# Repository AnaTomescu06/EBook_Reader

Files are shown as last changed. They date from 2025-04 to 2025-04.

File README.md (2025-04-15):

# OpenBook – Proiect TSC 2025

## Descriere generală

**OpenBook** este un dispozitiv portabil de tip e-book reader, conceput ca soluție open-source, eficientă energetic și scalabilă. Acesta se bazează pe microcontrolerul **ESP32-C6-WROOM**, având ca funcții principale afișarea de conținut pe un ecran e-paper și monitorizarea parametrilor de mediu (temperatură, umiditate, CO2, particule).

Dispozitivul permite salvarea datelor colectate pe un card microSD și oferă control prin intermediul unor butoane fizice.

## Diagramă bloc
Pollution Tracker

## Funcționalitate hardware

Dispozitivul este structurat în jurul modulului **ESP32-C3-WROOM**, care gestionează toate interfețele de comunicare cu componentele externe.

### ESP32-C3-WROOM
- Microcontroler principal cu suport pentru **Wi-Fi** și **BLE**
- Interfețe: **SPI**, **I2C**, **UART**
- Alimentare: **3.3V** prin LDO

### Sistem de alimentare
- **USB-C** pentru alimentare externă și comunicare
- **MCP73832** pentru managementul încărcării bateriei Li-Po
- **LDO 3.3V** pentru alimentarea logicii
- **DC-DC 5V** pentru alimentarea senzorilor PM și CO2

### Senzori
- **BME680** (I2C, 3.3V) - temperatură, umiditate, gaze
- **MH-Z19B** (UART, 5V) - CO2
- **PMSA003** (UART, 5V) - particule fine (PM2.5)

### Ecran
- **E-paper monocrom 1.5''** cu rezoluție 200x200 px
- Interfață SPI comună cu cardul SD

### Card SD
- Slot microSD pentru stocarea de date/text
- Interfață SPI

### Butoane
- 3 butoane tactile conectate la pinii GPIO pentru interacțiune cu utilizatorul

## Bill of Materials (BOM)

| Part | Device | Datasheet |
|---|---|---|
| CHG_LED | ADAFRUIT_LEDCHIP-LED0603 | [ADAFRUIT_LEDCHIP-LED0603](https://www.snapeda.com/parts/KP-1608SURCK/Kingbright/view-part/?ref=search&t=LED%200603) |
| SJ1 | SJ | [SJ](https://grabcad.com/library/solder-jumpers-1) |
| EPD_C5 | EAGLE-LTSPICE_CC0402 | [EAGLE-LTSPICE_CC0402](https://www.snapeda.com/parts/PGB1010603MR/Littelfuse/view-part/?ref=eda) |
| R3 | ESP32_WROVER_EAGLE-LTSPICE_RR0402 | (https://componentsearchengine.com/part-view/R0402%201%25%20100%20K%20(RC0402FR-07100KL)/YAGEO) |
| R1_PWRUSB | ESP32_WROVER_EAGLE-LTSPICE_RR0402 | (https://componentsearchengine.com/part-view/R0402%201%25%20100%20K%20(RC0402FR-07100KL) |
| C4_USB | EAGLE-LTSPICE_CC0402 | [EAGLE-LTSPICE_CC0402](https://componentsearchengine.com/part-view/CC0402MRX5R5BB106/YAGEO) |
| C1, C2, C6, C8, C9, C10, C_DELAY | ESP32_WROVER_EAGLE-LTSPICE_CC0402 | [ESP32_WROVER_EAGLE-LTSPICE_CC0402](https://componentsearchengine.com/part-view/CC0402MRX5R5BB106/YAGEO) |
| C3 | RCL_CPOL-EUCT3528 | [RCL_CPOL-EUCT3528](https://componentsearchengine.com/part-view/CC0402MRX5R5BB106/YAGEO) |
| R1, R1_PINH, R1_PINH1, R2_PINH, R2_PINH1, R4, R5, R6, R7, R8, R9, R10, R_BOOT, R_CHANGE, R_CL1, R_RESET | ESP32_WROVER_EAGLE-LTSPICE_RR0402 | [ESP32_WROVER_EAGLE-LTSPICE_RR0402](https://componentsearchengine.com/part-view/R0402%201%25%20100%20K%20(RC0402FR-07100KL)/YAGEO) |
| C7 | ESP32_WROVER_EAGLE-LTSPICE_CC0402 | [ESP32_WROVER_EAGLE-LTSPICE_CC0402](https://componentsearchengine.com/part-view/CC0402MRX5R5BB106/YAGEO) |
| J4 | 112A-TAAR-R03_ATTEND | [112A-TAAR-R03_ATTEND](https://store.comet.srl.ro/Catalogue/Product/43497/) |
| R_CAPACITOR | ESP32_WROVER_EAGLE-LTSPICE_RR0402 | [ESP32_WROVER_EAGLE-LTSPICE_RR0402](https://componentsearchengine.com/part-view/R0402%201%25%20100%20K%20(RC0402FR-07100KL)/YAGEO) |
| C5 | ESP32_WROVER_EAGLE-LTSPICE_CC0402 | [ESP32_WROVER_EAGLE-LTSPICE_CC0402](https://componentsearchengine.com/part-view/CC0402MRX5R5BB106/YAGEO) |
| EPD_C6, EPD_C7, EPD_C8, EPD_C9, EPD_C10, EPD_C11, EPD_C12 | EAGLE-LTSPICE_CC0402 | [EAGLE-LTSPICE_CC0402](https://componentsearchengine.com/part-view/CC0402MRX5R5BB106/YAGEO) |
| EPD_C1, EPD_C2 | ESP32_WROVER_EAGLE-LTSPICE_CC0402 | [ESP32_WROVER_EAGLE-LTSPICE_CC0402](https://componentsearchengine.com/part-view/CC0402MRX5R5BB106/YAGEO) |
| R2 | ESP32_WROVER_EAGLE-LTSPICE_RR0402 | [ESP32_WROVER_EAGLE-LTSPICE_RR0402](https://componentsearchengine.com/part-view/R0402%201%25%20100%20K%20(RC0402FR-07100KL)/YAGEO) |
| R1_BAT | ESP32_WROVER_EAGLE-LTSPICE_RR0402 | [ESP32_WROVER_EAGLE-LTSPICE_RR0402](https://componentsearchengine.com/part-view/R0402%201%25%20100%20K%20(RC0402FR-07100KL)/YAGEO) |
| Q1, Q2 | ESP32_WROVER_SPARKFUN-DISCRETESEMI_MOSFET_PCH-DMG2305UX-7 | [ESP32_WROVER_SPARKFUN-DISCRETESEMI_MOSFET_PCH-DMG2305UX-7](https://componentsearchengine.com/part-view/DMG2305UX-7/Diodes%20Incorporated) |
| R2_BAT | ESP32_WROVER_EAGLE-LTSPICE_RR0402 | [ESP32_WROVER_EAGLE-LTSPICE_RR0402](https://componentsearchengine.com/part-view/R0402%201%25%20100%20K%20(RC0402FR-07100KL)/YAGEO) |
| C5_USB | EAGLE-LTSPICE_CC0402 | [EAGLE-LTSPICE_CC0402](https://componentsearchengine.com/part-view/CC0402MRX5R5BB106/YAGEO) |
| C1_BAT, C1_BAT1, C1_BAT2, C2_BAT | ESP32_WROVER_EAGLE-LTSPICE_CC0402 | [ESP32_WROVER_EAGLE-LTSPICE_CC0402](https://componentsearchengine.com/part-view/CC0402MRX5R5BB106/YAGEO) |
| C4 | ESP32_WROVER_EAGLE-LTSPICE_CC0402 | [ESP32_WROVER_EAGLE-LTSPICE_CC0402](https://componentsearchengine.com/part-view/CC0402MRX5R5BB106/YAGEO) |
| R2-USB, R2-USB1 | ESP32_WROVER_EAGLE-LTSPICE_RR0402 | [ESP32_WROVER_EAGLE-LTSPICE_RR0402](https://componentsearchengine.com/part-view/R0402%201%25%20100%20K%20(RC0402FR-07100KL)/YAGEO) |
| L1 | 744043680IND_4828-WE-TPC_WRE | [744043680IND_4828-WE-TPC_WRE](https://eu.mouser.com/ProductDetail/Wurth-Elektronik/744043680?qs=PGXP4M47uW6VkZq%252BkzjrHA%3D%3D) |
| IC1 | BD5229G-TR | [BD5229G-TR](https://componentsearchengine.com/part-view/BD5229G-TR/ROHM%20Semiconductor) |
| SENSOR2 | ESP32_WROVER_BME680_BME680 | [ESP32_WROVER_BME680_BME680](https://www.snapeda.com/parts/BME680/Bosch/view-part/?welcome=home) |
| BUTTON_CUSYOMV1 |BUTTON_CUSYOMV1 | [BUTTON_CUSYOMV1](https://industry.panasonic.com/global/en/products/control/switch/light-touch/number/evqpuj02k) |
| C10_SUPERCAP | CPH3225A | [CPH3225A](https://www.snapeda.com/parts/CPH3225A/Seiko+Instruments/view-part/?ref=snap) |
| U3 | DS3231SN# | [DS3231SN#](https://www.snapeda.com/parts/DS3231SN%23/Analog+Devices/view-part/?ref=snap) |
| U2 | ESP32-C6-WROOM-1-N8 | [ESP32-C6-WROOM-1-N8](https://www.snapeda.com/parts/ESP32-C6-WROOM-1-N8/Espressif+Systems/view-part/?ref=eda) |
| PFMF.050.1 | ESP32C6_VARISTORCN1812 | [ESP32C6_VARISTORCN1812](https://www.mouser.co.uk/ProductDetail/EPCOS-TDK/B72520T0350K062?qs=dEfas%2FXlABIszF52uu7vrg%3D%3D) |
| D2, D7 | ESP32_WROVER_AVX---SD0805S020S1R0_AVX_SD0805S020S1R0_0_0AVX_SD0805S020S1R0_0_0 | [ESP32_WROVER_AVX---SD0805S020S1R0_AVX_SD0805S020S1R0_0_0AVX_SD0805S020S1R0_0_0](https://eu.mouser.com/ProductDetail/KYOCERA-AVX/SD0805S020S1R0?qs=jCA%252BPfw4LHbpkAoSnwrdjw%3D%3D) |
| U5 | ESP32_WROVER_SPARKFUN-IC-POWER_MCP73831 | [ESP32-C6-WROOM-1-N8](https://componentsearchengine.com/part-view/MCP73831T-2ATI%2FOT/Microchip) |
| J1 | FH34SRJ-24S-0.5SH_99_ | [FH34SRJ-24S-0.5SH_99_](https://componentsearchengine.com/part-view/XC6220A331MR-G/Torex) |
| U4 | MAX17048G+T10 | [MAX17048G+T10](https://www.snapeda.com/parts/MAX17048G+T10/Analog+Devices/view-part/?ref=snap) |
| D3, D4, D5 | MBR0530 | [MBR0530](https://www.snapeda.com/parts/MBR0530/Onsemi/view-part/?ref=snap) |
| D6, D8, D9, D10, D11, D12 | PGB1010603MR | [PGB1010603MR](https://www.snapeda.com/parts/PGB1010603MR/Littelfuse/view-part/?ref=snap) |
| J3 | QWIIC_CONNECTORJS-1MM | [QWIIC_CONNECTORJS-1MM](https://www.snapeda.com/parts/PRT-14417/SparkFun%20Electronics/view-part/?ref=search&t=qwiic) |
| J2 | SAMACSYS_PARTS_USB4110-GF-A | (https://componentsearchengine.com/part-view/USB4110-GF-A/GCT%20(GLOBAL%20CONNECTOR%20TECHNOLOGY) |
| Q3 | SI1308EDL-T1-GE3 | [SI1308EDL-T1-GE3](https://componentsearchengine.com/part-view/SI1308EDL-T1-GE3/Vishay) |
| TP1, TP2, TP3, TP4, TP5, TP6, TP7, TP8, TP9, TP10, TP11, TP12, TP13, TP14, TP15, TP16, TP17 | TPTP20R | [facute de mine] |
| D1 | USBLC6-2SC6Y | [USBLC6-2SC6Y](https://www.snapeda.com/parts/USBLC6-2SC6Y/STMicroelectronics/view-part/?ref=snap) |
| U1 | W25Q512JVEIQ | [W25Q512JVEIQ](https://www.snapeda.com/parts/W25Q512JVEIQ/Winbond+Electronics/view-part/?ref=snap) |
| IC4 | XC6220A331MR-G | [XC6220A331MR-G](https://componentsearchengine.com/part-view/XC6220A331MR-G/Torex) |

## Alocare pini ESP32-C3

| Pin ESP32-C3 | Componentă  | Funcție / Motiv |
|---|---|---|
| GPIO1 | BME680 | I2C - SDA |
| GPIO2 | BME680 | I2C - SCL |
| GPIO3 | PMSA003 | UART RX pentru senzor PM |
| GPIO4 | SD Card | SPI Chip Select (CS) |
| GPIO5 | E-Ink | Data/Command |
| GPIO6 | E-Ink & SD  | SPI Clock (SCK) |
| GPIO7 | E-Ink & SD  | SPI MOSI (date) |
| GPIO8 | Buton 1 | Control meniu / pagină |
| GPIO9 | Buton 2 | Control meniu / pagină |
| GPIO10 | E-Ink | SPI Chip Select (CS) |
| GPIO11 | Flash ext.  | CS rezervat, neutilizat momentan |
| GPIO12 | USB | USB D- |
| GPIO13 | USB | USB D+ |
| GPIO18 | MH-Z19B | UART TX pentru senzor CO2 |
| GPIO19 | Buton 3 | Confirmare / acțiune suplimentară  |

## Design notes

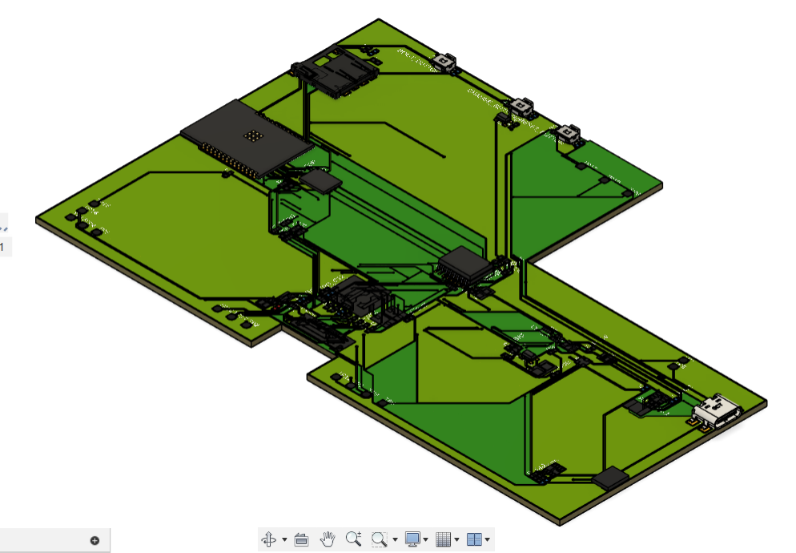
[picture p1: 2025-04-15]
Images/Screenshot 2025-04-15 091844.png

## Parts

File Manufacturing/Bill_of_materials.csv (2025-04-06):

BOOT_BUTTON | 36.07 | 115.33 | 180.00 | BUTTON_CUSYOMV1 | MYBUTTON
C1 | 18.81 | 107.10 | 90.00 |  | EAGLE-LTSPICE_C0402
C10 | 64.88 | 114.96 | 90.00 | 100nF | EAGLE-LTSPICE_C0402
C11 | 33.05 | 115.06 | 90.00 | 100nF | EAGLE-LTSPICE_C0402
C1_BAT | 92.31 | 28.88 | 90.00 | 4.7uF | ESP32_WROVER_EAGLE-LTSPICE_C0402
C1_BAT1 | 78.65 | 26.12 | 90.00 | 4.7uF | EAGLE-LTSPICE_C0402
C1_BAT2 | 167.29 | 58.42 | 90.00 | 4.7uF | EAGLE-LTSPICE_C0402
C2 | 20.80 | 107.17 | 90.00 |  | EAGLE-LTSPICE_C0402
C2_BAT | 88.52 | 28.88 | 90.00 | 4.7uF | EAGLE-LTSPICE_C0402
C3 | 137.11 | 45.80 | 90.00 | 100uF TANT | RCL_CT3528
C4 | 80.06 | 26.14 | 90.00 | 4.7uF/25V | ESP32_WROVER_EAGLE-LTSPICE_C0402
C4_USB | 90.42 | 28.90 | 90.00 | 100nF | ESP32_WROVER_EAGLE-LTSPICE_C0402
C5 | 169.02 | 14.68 | 90.00 | 1uF | EAGLE-LTSPICE_C0402
C5_USB | 94.23 | 28.90 | 90.00 | 4.7uF | ESP32_WROVER_EAGLE-LTSPICE_C0402
C6 | 80.02 | 114.96 | 90.00 | 100nF | EAGLE-LTSPICE_C0402
C7 | 159.19 | 57.10 | 90.00 |  | EAGLE-LTSPICE_C0402
C8 | 106.29 | 57.44 | 269.60 | CPH3225A | CAPCP3225X100N
C9 | 39.90 | 114.96 | 90.00 | 100nF | EAGLE-LTSPICE_C0402
CHANGE_BUTTON | 61.06 | 115.43 | 180.00 | BUTTON_CUSYOMV1 | MYBUTTON
CHG_LED | 130.94 | 57.55 | 90.00 |  | ADAFRUIT_CHIP-LED0603
C_DELAY | 81.59 | 32.52 | 90.00 | 100nF | EAGLE-LTSPICE_C0402
D1 | 164.18 | 56.82 | 0.00 | USBLC6-2SC6Y | SOT95P280X145-6N
D10 | 59.43 | 45.20 | 90.00 | PGB1010603MR | DIOC1608X36N
D11 | 44.81 | 55.80 | 90.00 | PGB1010603MR | DIOC1608X36N
D12 | 23.69 | 105.10 | 0.00 | PGB1010603MR | DIOC1608X36N
D2 | 100.11 | 70.31 | 0.00 | ESP32_WROVER_AVX---SD0805S020S1R0_AVX_SD0805S020S1R0_0_0AVX_SD0805S020S1R0_0_0 | ESP32_WROVER_AVX---SD0805S020S1R0_AVX_SD0805S020S1R0_0
D3 | 88.43 | 41.20 | 180.00 | MBR0530 | SOD3716X135N
D4 | 97.57 | 33.70 | 0.00 | MBR0530 | SOD3716X135N
D5 | 97.61 | 37.50 | 180.00 | MBR0530 | SOD3716X135N
D6 | 57.68 | 45.22 | 90.00 | PGB1010603MR | DIOC1608X36N
D7 | 127.36 | 46.91 | 90.00 | ESP32_WROVER_AVX---SD0805S020S1R0_AVX_SD0805S020S1R0_0_0AVX_SD0805S020S1R0_0_0 | ESP32_WROVER_AVX---SD0805S020S1R0_AVX_SD0805S020S1R0_0
D8 | 54.46 | 45.22 | 90.00 | PGB1010603MR | DIOC1608X36N
D9 | 81.65 | 29.63 | 0.00 | PGB1010603MR | DIOC1608X36N
EPD_C1 | 96.14 | 28.90 | 90.60 | 1uF/50V | ESP32_WROVER_EAGLE-LTSPICE_C0402
EPD_C10 | 101.43 | 38.32 | 90.90 | 1uF/50V | ESP32_WROVER_EAGLE-LTSPICE_C0402
EPD_C11 | 86.61 | 28.92 | 90.00 | 1uF/50V | ESP32_WROVER_EAGLE-LTSPICE_C0402
EPD_C12 | 79.77 | 32.52 | 90.00 | 1uF/50V | ESP32_WROVER_EAGLE-LTSPICE_C0402
EPD_C2 | 74.35 | 21.00 | 0.00 | 1uF/50V | ESP32_WROVER_EAGLE-LTSPICE_C0402
EPD_C5 | 76.70 | 20.04 | 90.00 | 0.1uF/50V | EAGLE-LTSPICE_C0402
EPD_C6 | 139.46 | 59.50 | 90.00 | 1uF/50V | ESP32_WROVER_EAGLE-LTSPICE_C0402
EPD_C7 | 64.18 | 109.48 | 90.00 | 1uF/50V | ESP32_WROVER_EAGLE-LTSPICE_C0402
EPD_C8 | 100.09 | 68.38 | 0.00 | 1uF/50V | ESP32_WROVER_EAGLE-LTSPICE_C0402
EPD_C9 | 57.60 | 41.58 | 90.00 | 1uF/50V | ESP32_WROVER_EAGLE-LTSPICE_C0402
IC1 | 131.95 | 46.82 | 0.00 | BD5229G-TR | SOT95P280X125-5N
IC4 | 61.09 | 109.22 | 0.00 | XC6220A331MR-G | SOT95P280X120-5N
J1 | 91.15 | 20.52 | 0.00 | FH34SRJ-24S-0.5SH_99_ | FH34SRJ24S05SH99
J2 | 177.96 | 60.66 | 90.10 | SAMACSYS_PARTS_USB4110-GF-A | SAMACSYS_PARTS_USB4110GFA
J3 | 179.19 | 25.66 | 90.00 | QWIIC_RIGHT_ANGLE | JST04_1MM_RA
J4 | 20.45 | 95.03 | 270.00 | 112A-TAAR-R03_ATTEND | 112ATAARR03ATTEND
L1 | 88.47 | 36.35 | 0.00 | 68uH | IND_4828-WE-TPC_WRE
PFMF.050.1 | 163.34 | 50.40 | 0.00 | ESP32C6_VARISTORCN1812 | ESP32C6_VARISTOR_CT/CN1812
Q1 | 84.51 | 32.61 | 270.00 | 20V/4.2A/52mΩ/1.4W | ESP32_WROVER_SPARKFUN-DISCRETESEMI_SOT23-3
Q2 | 141.68 | 54.61 | 0.00 | 20V/4.2A/52mΩ/1.4W | ESP32_WROVER_SPARKFUN-DISCRETESEMI_SOT23-3
Q3 | 75.41 | 24.38 | 90.00 | SI1308EDL-T1-GE3 | SOT65P210X110-3N
R1 | 164.88 | 53.00 | 0.00 |  | ESP32_WROVER_EAGLE-LTSPICE_R0402
R1-PINH | 59.10 | 41.60 | 90.00 | 10K | ESP32_WROVER_EAGLE-LTSPICE_R0402
R1-PINH1 | 54.81 | 41.52 | 90.00 | 10K | ESP32_WROVER_EAGLE-LTSPICE_R0402
R10 | 57.30 | 114.96 | 90.00 | 10K | ESP32_WROVER_EAGLE-LTSPICE_R0402
R1_BAT | 84.73 | 28.88 | 90.00 | 200 | ESP32_WROVER_EAGLE-LTSPICE_R0402
R1_PWRUSB | 103.95 | 56.84 | 90.00 | 100K | ESP32_WROVER_EAGLE-LTSPICE_R0402
R2 | 164.86 | 54.26 | 0.00 | 2.2 | ESP32_WROVER_EAGLE-LTSPICE_R0402
R2-PINH | 87.61 | 31.69 | 0.00 | 10K | ESP32_WROVER_EAGLE-LTSPICE_R0402
R2-PINH1 | 99.45 | 54.12 | 0.00 | 10K | ESP32_WROVER_EAGLE-LTSPICE_R0402
R2-USB | 140.65 | 46.58 | 90.00 | 5k1 | ESP32_WROVER_EAGLE-LTSPICE_R0402
R2-USB1 | 31.38 | 49.40 | 90.00 | 5k1 | ESP32_WROVER_EAGLE-LTSPICE_R0402
R2_BAT | 125.54 | 46.88 | 90.00 | 2K | ESP32_WROVER_EAGLE-LTSPICE_R0402
R3 | 72.38 | 114.96 | 90.00 | 0.47 | ESP32_WROVER_EAGLE-LTSPICE_R0402
R4 | 166.64 | 14.76 | 90.00 | 10k | ESP32_WROVER_EAGLE-LTSPICE_R0402
R5 | 130.92 | 56.06 | 0.00 | 10K | ESP32_WROVER_EAGLE-LTSPICE_R0402
R6 | 167.84 | 14.71 | 90.00 | 10K | ESP32_WROVER_EAGLE-LTSPICE_R0402
R7 | 127.96 | 43.86 | 0.00 | 10K | ESP32_WROVER_EAGLE-LTSPICE_R0402
R8 | 133.88 | 52.56 | 90.00 | 10K | ESP32_WROVER_EAGLE-LTSPICE_R0402
R9 | 127.20 | 57.46 | 0.00 | 10K | ESP32_WROVER_EAGLE-LTSPICE_R0402
RESET_BUTTON | 76.15 | 115.52 | 180.00 | BUTTON_CUSYOMV1 | MYBUTTON
R_BOOT | 103.99 | 67.40 | 90.00 | 10K | ESP32_WROVER_EAGLE-LTSPICE_R0402
R_CAPACITOR | 43.15 | 55.74 | 90.00 | 15 | ESP32_WROVER_EAGLE-LTSPICE_R0402
R_CHANGE | 98.12 | 28.94 | 90.00 | 10K | ESP32_WROVER_EAGLE-LTSPICE_R0402
R_CL1 | 165.43 | 14.78 | 90.00 | 10K | ESP32_WROVER_EAGLE-LTSPICE_R0402
R_RESET | 79.04 | 23.04 | 0.00 | 10K | ESP32_WROVER_EAGLE-LTSPICE_R0402
SENSOR2 | 167.31 | 19.42 | 89.80 | BME688 | ESP32_WROVER_BME680_PSON80P300X300X100-8N
SJ1 | 73.52 | 19.02 | 0.00 |  | SJ
TP1 | 110.66 | 10.14 | 0.00 | TPTP20R | TP20R
TP10 | 94.19 | 108.94 | 0.00 | TPTP20R | TP20R
TP11 | 105.84 | 10.14 | 0.00 | TPTP20R | TP20R
TP12 | 86.54 | 109.04 | 0.00 | TPTP20R | TP20R
TP13 | 17.99 | 11.84 | 0.00 | TPTP20R | TP20R
TP14 | 17.94 | 15.54 | 0.00 | TPTP20R | TP20R
TP15 | 17.99 | 19.44 | 0.00 | TPTP20R | TP20R
TP16 | 67.44 | 10.04 | 0.00 | TPTP20R | TP20R
TP17 | 71.99 | 10.04 | 0.00 | TPTP20R | TP20R
TP2 | 76.68 | 10.14 | 0.00 | TPTP20R | TP20R
TP3 | 115.60 | 10.14 | 0.00 | TPTP20R | TP20R
TP4 | 22.12 | 11.51 | 0.00 | TPTP20R | TP20R
TP5 | 26.34 | 11.84 | 0.00 | TPTP20R | TP20R
TP6 | 120.76 | 10.34 | 0.00 | TPTP20R | TP20R
TP7 | 157.59 | 71.22 | 0.00 | TPTP20R | TP20R
TP8 | 157.71 | 67.82 | 0.00 | TPTP20R | TP20R
TP9 | 101.73 | 108.92 | 0.00 | TPTP20R | TP20R
U1 | 48.69 | 62.16 | 0.00 | W25Q512JVEIQ | SON127P600X800X80-9N
U2 | 28.20 | 62.04 | 90.00 | ESP32-C6-WROOM-1-N8 | XCVR_ESP32-C6-WROOM-1-N8
U3 | 96.75 | 61.30 | 270.00 | DS3231SN# | SOIC127P1032X265-16N
U4 | 144.85 | 59.12 | 0.00 | MAX17048G+T10 | SON50P200X200X80-9N
U6 | 135.26 | 56.79 | 90.00 | MCP73831 | ESP32_WROVER_SPARKFUN-IC-POWER_SOT23-5

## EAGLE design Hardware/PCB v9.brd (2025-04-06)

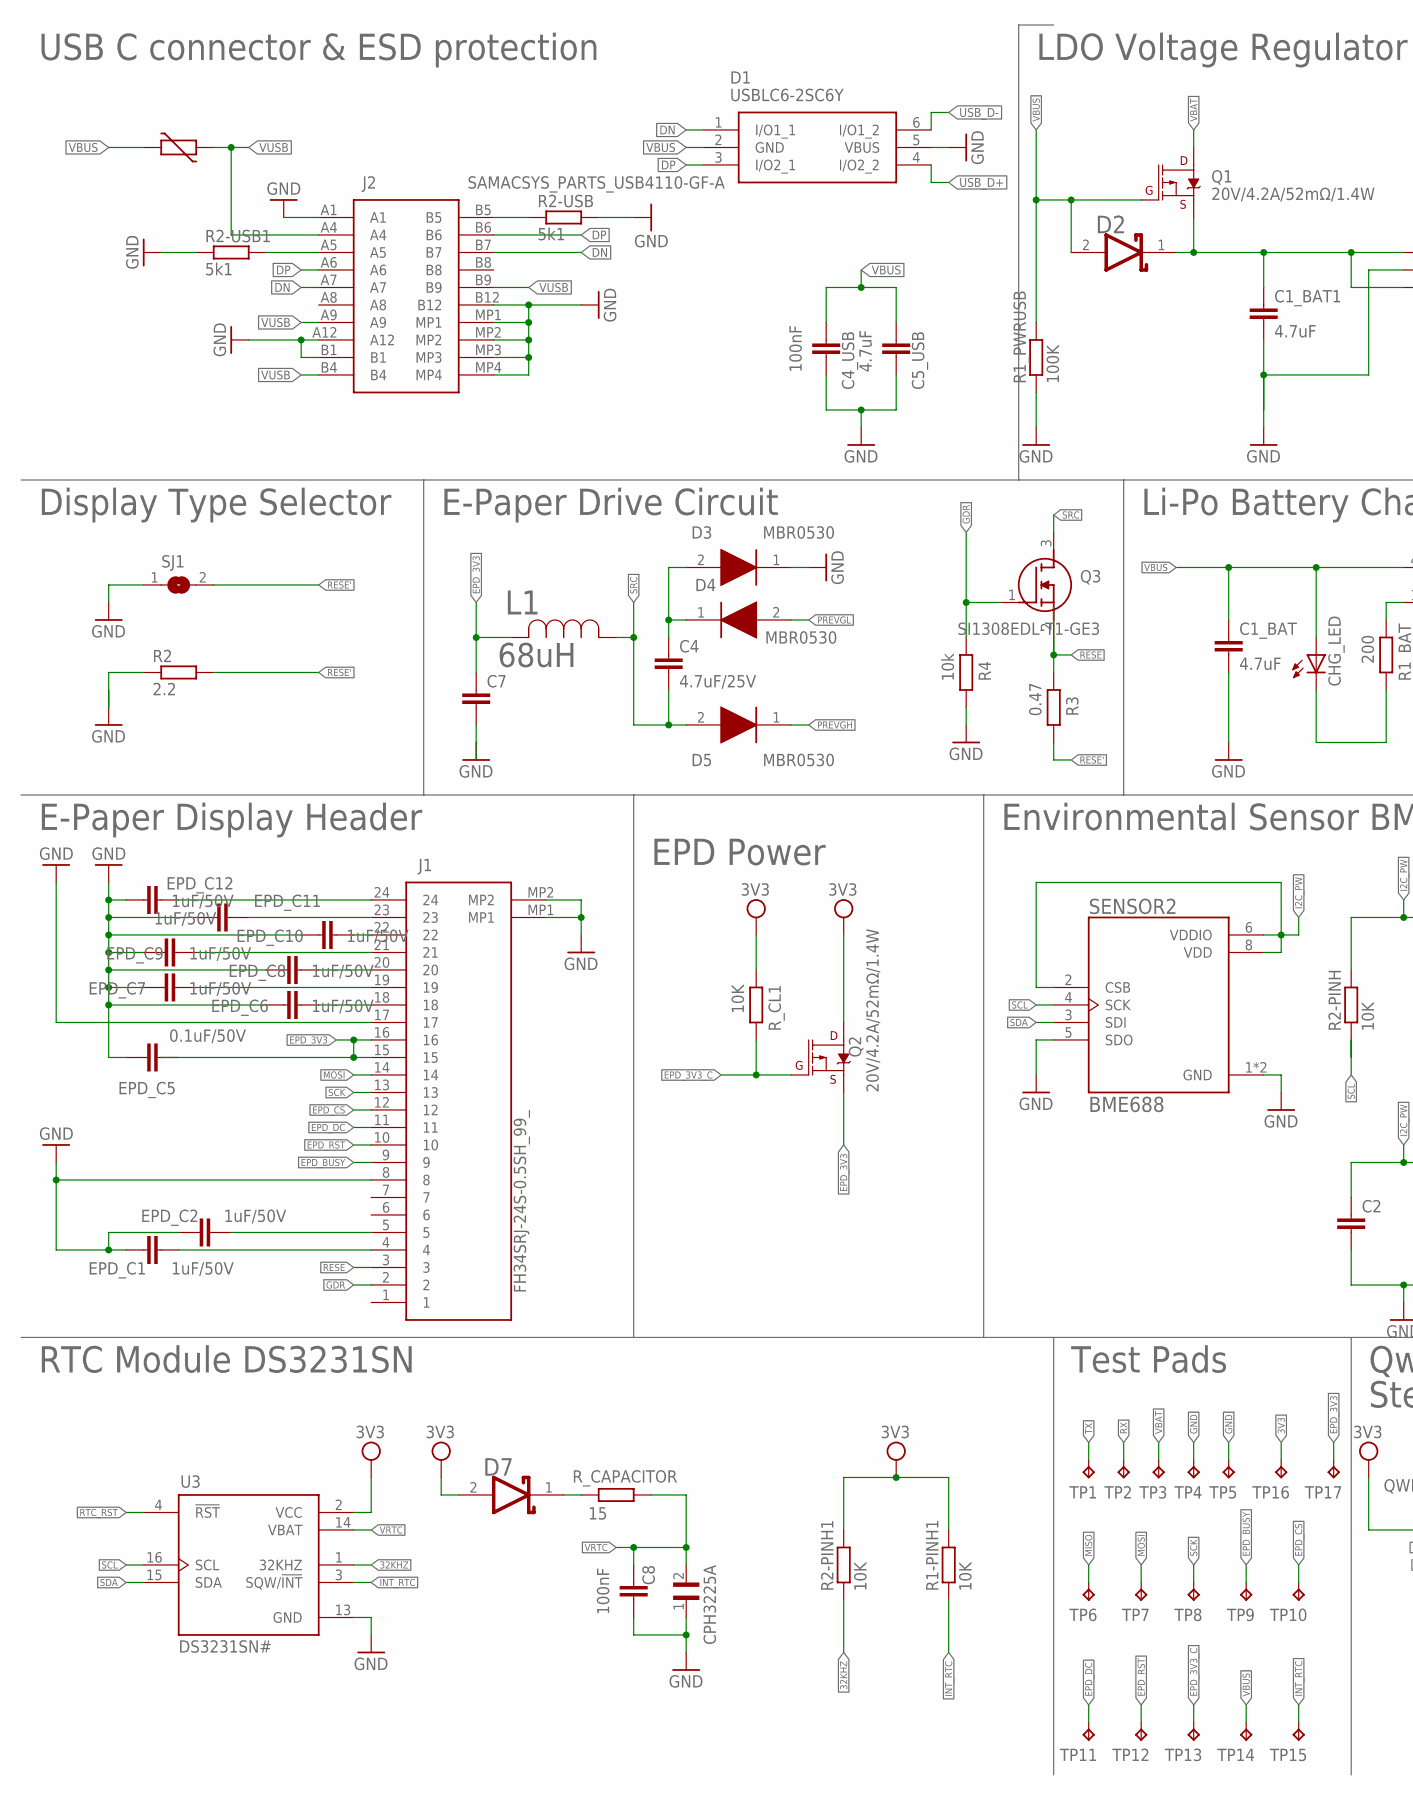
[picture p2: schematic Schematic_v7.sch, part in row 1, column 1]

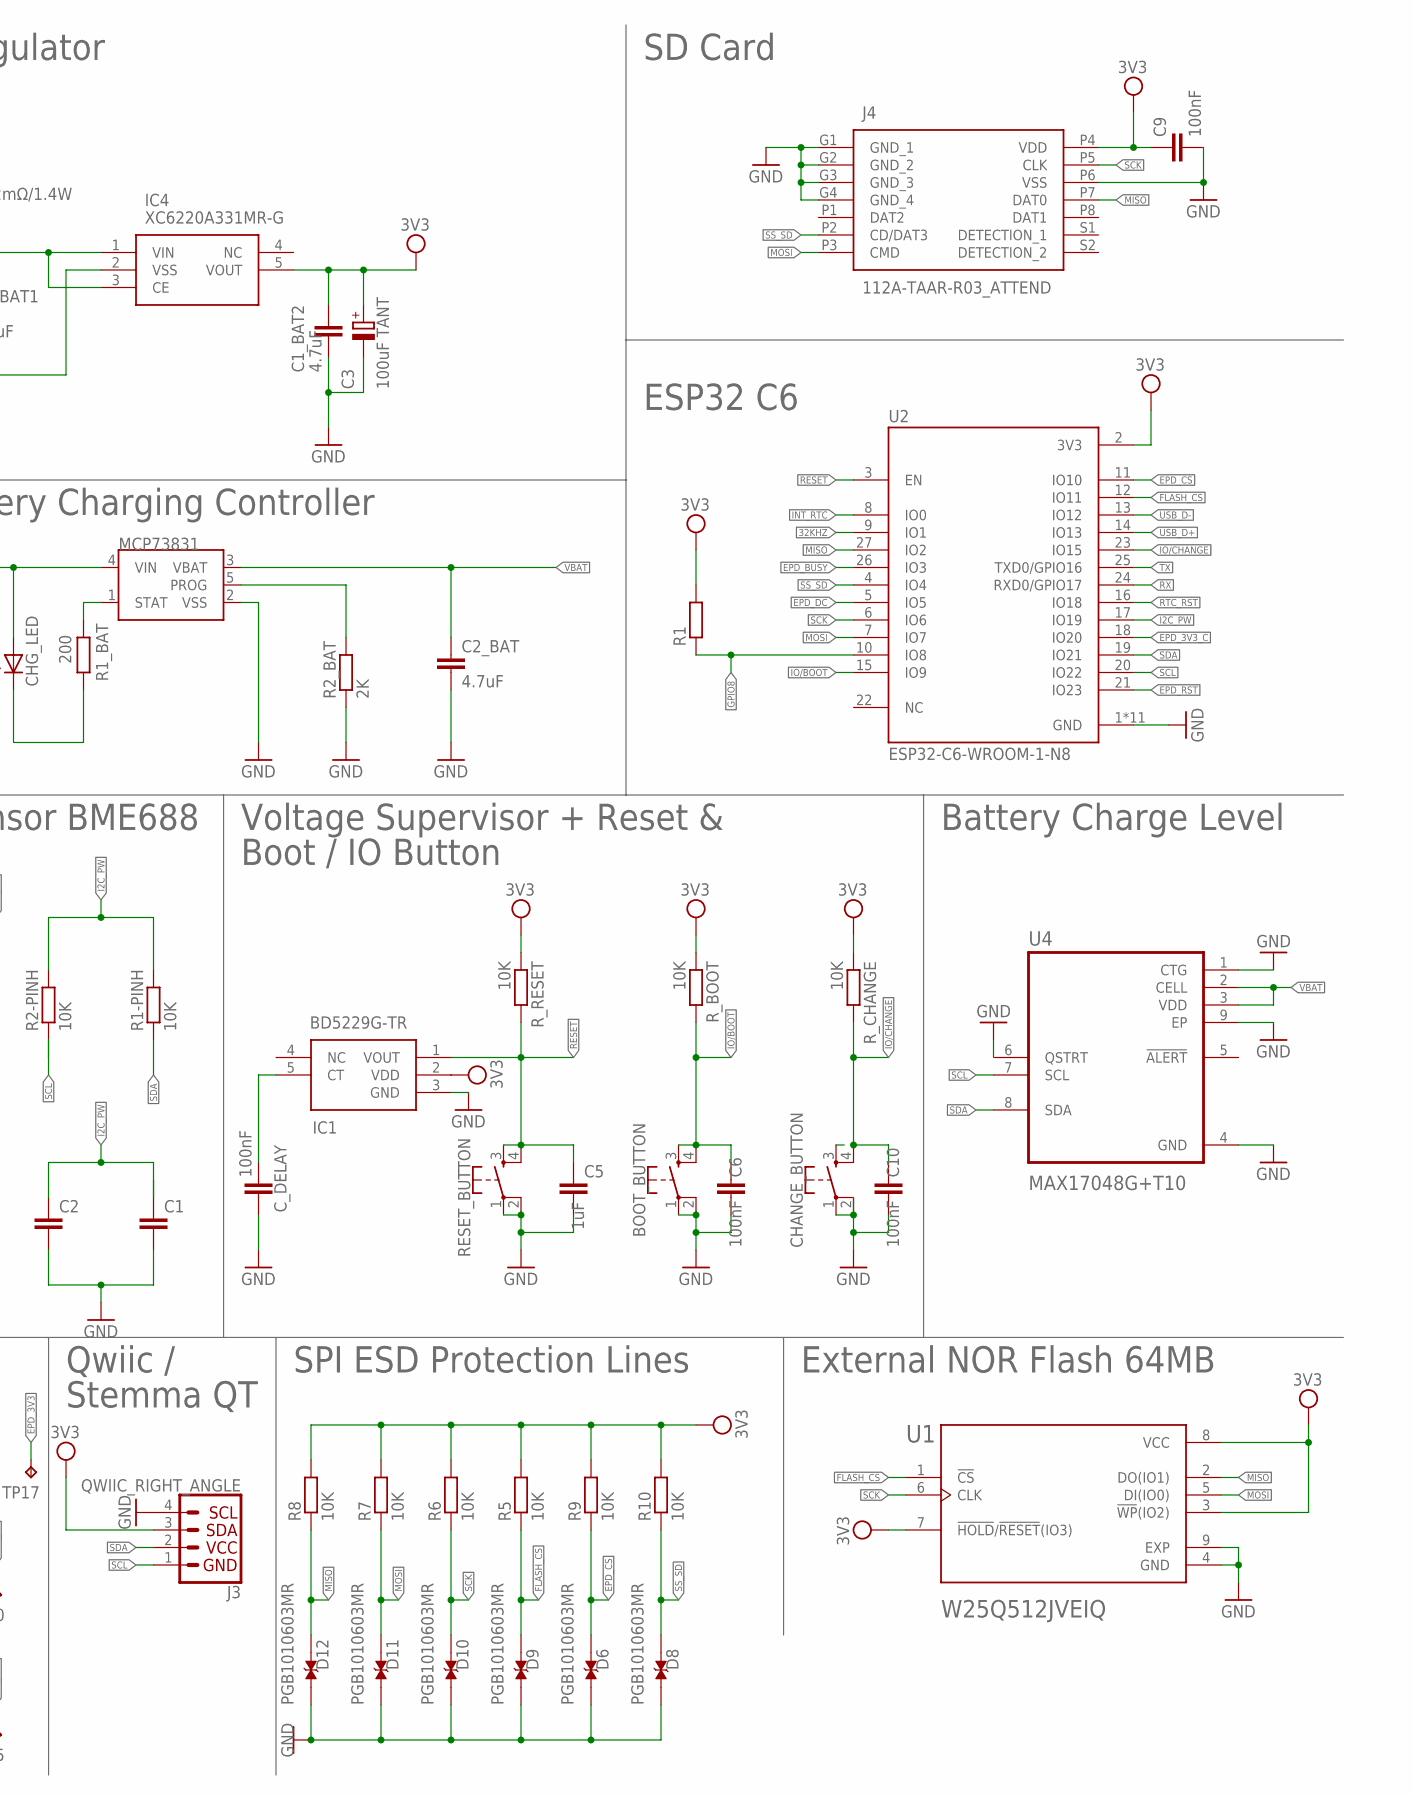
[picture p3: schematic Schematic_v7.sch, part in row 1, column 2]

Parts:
BOOT_BUTTON: BUTTON_CUSYOMV1; MYBUTTON
C1, C2, C7: EAGLE-LTSPICE_CC0402; EAGLE-LTSPICE_C0402
C1_BAT, C5_USB: 4.7uF; ESP32_WROVER_EAGLE-LTSPICE_C0402
C1_BAT1, C1_BAT2, C2_BAT: 4.7uF; EAGLE-LTSPICE_C0402
C3: 100uF TANT; RCL_CT3528
C4: 4.7uF/25V; ESP32_WROVER_EAGLE-LTSPICE_C0402
C4_USB: 100nF; ESP32_WROVER_EAGLE-LTSPICE_C0402
C5: 1uF; EAGLE-LTSPICE_C0402
C6, C9, C10, C11: 100nF; EAGLE-LTSPICE_C0402
C8: CPH3225A; CAPCP3225X100N
CHANGE_BUTTON: BUTTON_CUSYOMV1; MYBUTTON
CHG_LED: ADAFRUIT_LEDCHIP-LED0603; ADAFRUIT_CHIP-LED0603
C_DELAY: 100nF; EAGLE-LTSPICE_C0402
D1: USBLC6-2SC6Y; SOT95P280X145-6N
D2, D7: ESP32_WROVER_AVX---SD0805S020S1R0_AVX_SD0805S020S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; ESP32_WROVER_AVX---SD0805S020S1R0_AVX_SD0805S020S1R0_0
D3, D4, D5: MBR0530; SOD3716X135N
D6, D8, D9, D10, D11, D12: PGB1010603MR; DIOC1608X36N
EPD_C1, EPD_C2, EPD_C6, EPD_C7, EPD_C8, EPD_C9, EPD_C10, EPD_C11, EPD_C12: 1uF/50V; ESP32_WROVER_EAGLE-LTSPICE_C0402
EPD_C5: 0.1uF/50V; EAGLE-LTSPICE_C0402
IC1: BD5229G-TR; SOT95P280X125-5N
IC4: XC6220A331MR-G; SOT95P280X120-5N
J1: FH34SRJ-24S-0.5SH_99_; FH34SRJ24S05SH99
J2: SAMACSYS_PARTS_USB4110-GF-A; SAMACSYS_PARTS_USB4110GFA
J3: QWIIC_RIGHT_ANGLE; JST04_1MM_RA
J4: 112A-TAAR-R03_ATTEND; 112ATAARR03ATTEND
L1: 68uH; IND_4828-WE-TPC_WRE
PFMF.050.1: ESP32C6_VARISTORCN1812; ESP32C6_VARISTOR_CT/CN1812
Q1, Q2: 20V/4.2A/52mΩ/1.4W; ESP32_WROVER_SPARKFUN-DISCRETESEMI_SOT23-3
Q3: SI1308EDL-T1-GE3; SOT65P210X110-3N
R1: ESP32_WROVER_EAGLE-LTSPICE_RR0402; ESP32_WROVER_EAGLE-LTSPICE_R0402
R1-PINH, R1-PINH1, R2-PINH, R2-PINH1, R5, R6, R7, R8, R9, R10: 10K; ESP32_WROVER_EAGLE-LTSPICE_R0402
R1_BAT: 200; ESP32_WROVER_EAGLE-LTSPICE_R0402
R1_PWRUSB: 100K; ESP32_WROVER_EAGLE-LTSPICE_R0402
R2: 2.2; ESP32_WROVER_EAGLE-LTSPICE_R0402
R2-USB, R2-USB1: 5k1; ESP32_WROVER_EAGLE-LTSPICE_R0402
R2_BAT: 2K; ESP32_WROVER_EAGLE-LTSPICE_R0402
R3: 0.47; ESP32_WROVER_EAGLE-LTSPICE_R0402
R4: 10k; ESP32_WROVER_EAGLE-LTSPICE_R0402
RESET_BUTTON: BUTTON_CUSYOMV1; MYBUTTON
R_BOOT: 10K; ESP32_WROVER_EAGLE-LTSPICE_R0402
R_CAPACITOR: 15; ESP32_WROVER_EAGLE-LTSPICE_R0402
R_CHANGE: 10K; ESP32_WROVER_EAGLE-LTSPICE_R0402
R_CL1: 10K; ESP32_WROVER_EAGLE-LTSPICE_R0402
R_RESET: 10K; ESP32_WROVER_EAGLE-LTSPICE_R0402
SENSOR2: BME688; ESP32_WROVER_BME680_PSON80P300X300X100-8N
SJ1: SJ
TP1, TP2, TP3, TP4, TP5, TP6, TP7, TP8, TP9, TP10, TP11, TP12, TP13, TP14, TP15, TP16, TP17: TPTP20R; TP20R
U1: W25Q512JVEIQ; SON127P600X800X80-9N
U2: ESP32-C6-WROOM-1-N8; XCVR_ESP32-C6-WROOM-1-N8
U3: DS3231SN#; SOIC127P1032X265-16N
U4: MAX17048G+T10; SON50P200X200X80-9N
U6: MCP73831; ESP32_WROVER_SPARKFUN-IC-POWER_SOT23-5

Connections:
3V3: C1_BAT2.1, C3.+, C9.1, D7.2 (ANODE), IC1.2 (VDD), IC4.5 (VOUT), J3.3, J4.P4 (VDD), Q2.3 (D), R1.2, R1-PINH1.2, R2-PINH1.2, R5.2, R6.2, R7.2, R8.2, R9.2, R10.2, R_BOOT.1, R_CHANGE.1, R_CL1.2, R_RESET.1, TP16.TP, U1.3 (!WP!(IO2)), U1.7 (!HOLD!/!RESET!(IO3)), U1.8 (VCC), U2.2 (3V3), U3.2 (VCC)
32KHZ: R2-PINH1.1, U2.9 (IO1), U3.1 (32KHZ)
DN: D1.1 (I/O1_1), J2.A7, J2.B7
DP: D1.3 (I/O2_1), J2.A6, J2.B6
EPD_3V3: C7.1, EPD_C5.2, J1.15, J1.16, L1.2, Q2.2 (S), TP17.TP
EPD_3V3_C: Q2.1 (G), R_CL1.1, TP13.TP, U2.18 (IO20)
EPD_BUSY: J1.9, TP9.TP, U2.26 (IO3)
EPD_CS: D6.2, J1.12, R9.1, TP10.TP, U2.11 (IO10)
EPD_DC: J1.11, TP11.TP, U2.5 (IO5)
EPD_RST: J1.10, TP12.TP, U2.21 (IO23)
FLASH_CS: D9.2, R5.1, U1.1 (!CS), U2.12 (IO11)
GDR: J1.2, Q3.1 (G), R4.2
GND: BOOT_BUTTON.1, BOOT_BUTTON.2, C1.2, C1_BAT.2, C1_BAT1.2, C1_BAT2.2, C2.2, C2_BAT.2, C3.-, C4_USB.2, C5.2, C5_USB.2, C6.2, C7.2, C8.1, C9.2, C10.2, C11.2, CHANGE_BUTTON.1, CHANGE_BUTTON.2, C_DELAY.2, D1.5 (VBUS), D3.1 (K), EPD_C1.2, EPD_C2.2, EPD_C5.1, EPD_C6.2, EPD_C7.2, EPD_C8.2, EPD_C9.2, EPD_C10.2, EPD_C11.2, EPD_C12.2, IC1.3 (GND), IC4.2 (VSS), J1.8, J1.17, J1.MP1, J1.MP2, J2.A1, J2.A12, J2.B1, J2.B12, J2.MP1, J2.MP2, J2.MP3, J2.MP4, J3.4, J4.G1 (GND_1), J4.G2 (GND_2), J4.G3 (GND_3), J4.G4 (GND_4), J4.P6 (VSS), R1_PWRUSB.1, R2.1, R2-USB.2, R2-USB1.1, R2_BAT.1, R4.1, RESET_BUTTON.1, RESET_BUTTON.2, SENSOR2.1 (GND), SENSOR2.5 (SDO), SENSOR2.7 (GND), SJ1.1, TP4.TP, TP5.TP, U1.4 (GND), U1.9 (EXP), U2.1 (GND), U2.28 (GND), U2.29_1 (GND), U2.29_2 (GND), U2.29_3 (GND), U2.29_4 (GND), U2.29_5 (GND), U2.29_6 (GND), U2.29_7 (GND), U2.29_8 (GND), U2.29_9 (GND), U3.13 (GND), U4.1 (CTG), U4.4 (GND), U4.6 (QSTRT), U4.9 (EP), U6.2 (VSS)
GPIO8: R1.1, U2.10 (IO8)
I2C_PW: C1.1, C2.1, R1-PINH.2, R2-PINH.2, SENSOR2.2 (CSB), SENSOR2.6 (VDDIO), SENSOR2.8 (VDD), U2.17 (IO19)
INT_RTC: R1-PINH1.1, TP15.TP, U2.8 (IO0), U3.3 (SQW/!INT)
IO/BOOT: BOOT_BUTTON.3, BOOT_BUTTON.4, C6.1, R_BOOT.2, U2.15 (IO9)
IO/CHANGE: C10.1, CHANGE_BUTTON.4, R_CHANGE.2, U2.23 (IO15)
MISO: D6.1, D8.1, D9.1, D10.1, D11.1, D12.1, D12.2, J4.P7 (DAT0), R8.1, TP6.TP, U1.2 (DO(IO1)), U2.27 (IO2)
MOSI: D11.2, J1.14, J4.P3 (CMD), R7.1, TP7.TP, U1.5 (DI(IO0)), U2.7 (IO7)
unnamed: J2.A5, R2-USB1.2
unnamed: J2.B5, R2-USB.1
unnamed: C1_BAT1.1, D2.1 (CATHODE), IC4.1 (VIN), IC4.3 (CE), Q1.2 (S)
unnamed: C4.1, D3.2 (A), D4.1 (K)
unnamed: CHG_LED.C, R1_BAT.1
unnamed: R1_BAT.2, U6.1 (STAT)
unnamed: EPD_C12.1, J1.24
unnamed: R2_BAT.2, U6.5 (PROG)
unnamed: EPD_C10.1, J1.22
unnamed: EPD_C11.1, J1.23
unnamed: EPD_C9.1, J1.21
unnamed: EPD_C8.1, J1.20
unnamed: EPD_C7.1, J1.19
unnamed: EPD_C2.1, J1.5
unnamed: EPD_C1.1, J1.4
unnamed: EPD_C6.1, J1.18
unnamed: C_DELAY.1, IC1.5 (CT)
unnamed: D7.1 (CATHODE), R_CAPACITOR.2
PREVGH: D5.1 (K)
PREVGL: D4.2 (A)
RESE: J1.3, Q3.2 (S), R3.2
RESE': R2.2, R3.1, SJ1.2
RESET: C5.1, IC1.1 (VOUT), RESET_BUTTON.3, RESET_BUTTON.4, R_RESET.2, U2.3 (EN)
RTC_RST: U2.16 (IO18), U3.4 (!RST)
RX: TP2.TP, U2.24 (RXD0/GPIO17)
SCK: D10.2, J1.13, J4.P5 (CLK), R6.1, TP8.TP, U1.6 (CLK), U2.6 (IO6)
SCL: J3.1, R2-PINH.1, SENSOR2.4 (SCK), U2.20 (IO22), U3.16 (SCL), U4.7 (SCL)
SDA: J3.2, R1-PINH.1, SENSOR2.3 (SDI), U2.19 (IO21), U3.15 (SDA), U4.8 (SDA)
SRC: C4.2, D5.2 (A), L1.1, Q3.3 (D)
SS_SD: D8.2, J4.P2 (CD/DAT3), R10.1, U2.4 (IO4)
TX: TP1.TP, U2.25 (TXD0/GPIO16)
USB_D+: D1.4 (I/O2_2), U2.14 (IO13)
USB_D-: D1.6 (I/O1_2), U2.13 (IO12)
VBAT: C2_BAT.1, Q1.3 (D), TP3.TP, U4.2 (CELL), U4.3 (VDD), U6.3 (VBAT)
VBUS: C1_BAT.1, C4_USB.1, C5_USB.1, CHG_LED.A, D1.2 (GND), D2.2 (ANODE), PFMF.050.1.2, Q1.1 (G), R1_PWRUSB.2, TP14.TP, U6.4 (VIN)
VRTC: C8.2, C11.1, R_CAPACITOR.1, U3.14 (VBAT)
VUSB: J2.A4, J2.A9, J2.B4, J2.B9, PFMF.050.1.1

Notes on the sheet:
USB C connector & ESD protection
LDO Voltage Regulator
SD Card
Display Type Selector
E-Paper Drive Circuit
Li-Po Battery Charging Controller
ESP32 C6
E-Paper Display Header
EPD Power
Environmental Sensor BME688
Voltage Supervisor + Reset &
Boot / IO Button
Battery Charge Level
RTC Module DS3231SN
Test Pads
Qwiic /
Stemma QT
SPI ESD Protection Lines
External NOR Flash 64MB

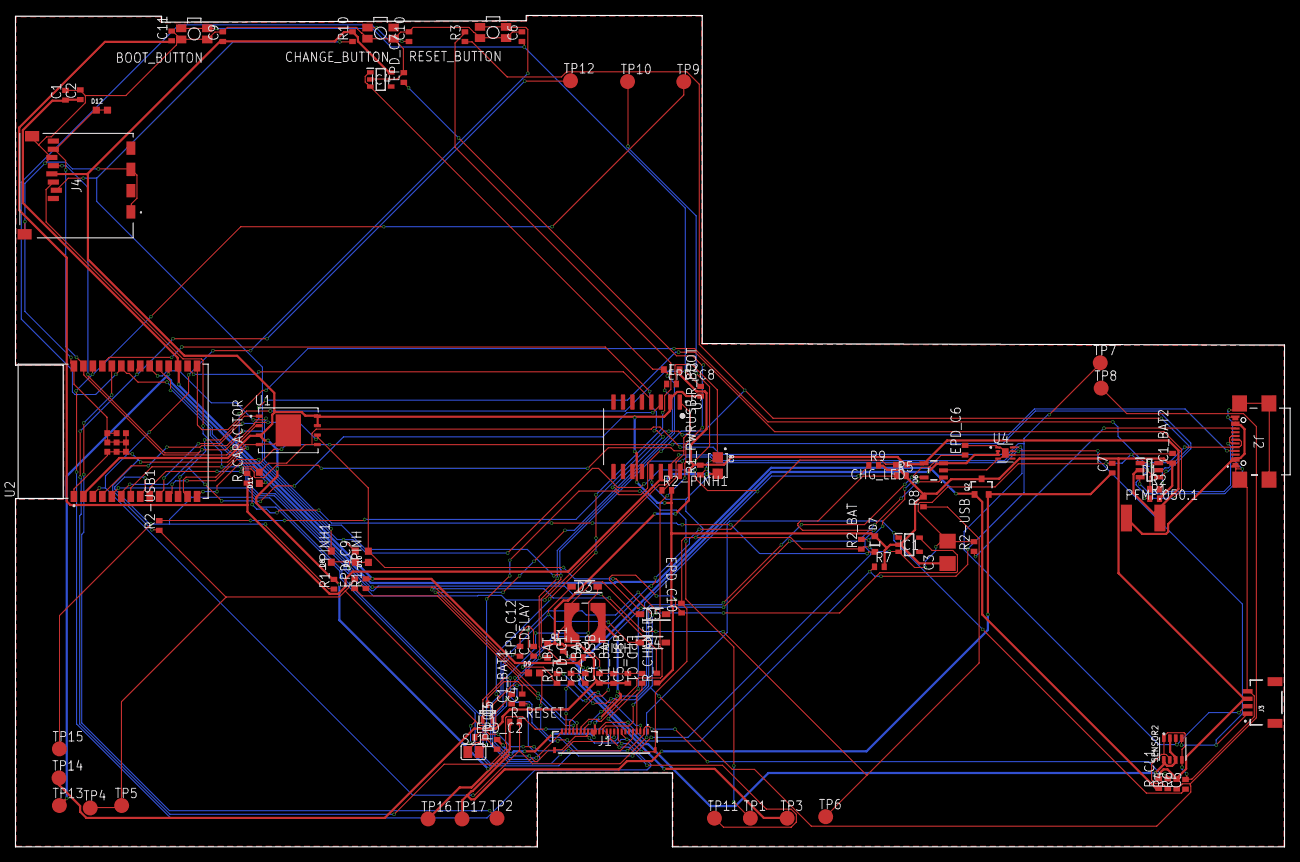
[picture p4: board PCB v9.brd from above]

Board: 2 copper layers, 170.2 x 111.5 mm, 103 parts (0 on the bottom side), 55 nets.

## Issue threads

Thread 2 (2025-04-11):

Lipsa link-uri furnizori in BOM

Matei4GHz, 2025-04-11:
În fișierul **Bill_of_materials.csv** cat si in BOM-ul din README.md, lipsește secțiunea cu linkuri către furnizori pentru procurarea componentelor.

### Recomandări:
- Adaugă in tabel linkuri către furnizori de încredere pentru fiecare componentă din BOM (de exemplu, Mouser, Digi-Key).

Matei4GHz, 2025-04-11:
Tot in BOM, link-urile catre datasheet-urile componentelor nu sunt valide.

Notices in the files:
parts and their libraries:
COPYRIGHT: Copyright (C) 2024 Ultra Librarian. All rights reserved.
